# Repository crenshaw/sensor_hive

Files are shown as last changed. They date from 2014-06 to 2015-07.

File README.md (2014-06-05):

# Sensor Hive

Another chapter in the Internet of Things.  Sensing the world and pushing data to the cloud.

## About

Buildings are responsible for up to 40% of energy use.  Students and
faculty at the University of Portland are working towards a low-cost
solution for sensing building lighting systems in order to find ways
to provide more efficient lighting.

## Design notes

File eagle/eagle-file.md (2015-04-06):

## Eagle
#### This directory contains all relevant files for the manufacturing of the PCB for the Scio DAQ.

### `Final Gerber Output`
 - This directory contains the output files, which are sent to a manufacturer to produce the PCB for Scio. These can be viewed in `.txt` format (not useful), or using a gerber file viewer (available online).

### `PCB Final Design`
 - This directory contains all Eagle CAD design files. These can be viewed using Eagle. 

### `Bill of Materials`
 - This is an excel (`.xlsx`) file containing all required components needed for the PCB. Part names in file match the parts listed in `.brd` (Board) file, located in the `PCB Final Design` directory. These can be purchased using the links provided in the file.

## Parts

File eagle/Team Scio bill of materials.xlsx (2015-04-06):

Qty | Value | Device | Package | Description | Source
6 | .01uF | CAP_CERAMIC0805 | 805 | Ceramic Capacitors
2 | .1uF | C-US025-025X050 | C025-025X050 | CAPACITOR, American symbol
12 | 10K | R-US_M1206 | M1206 | RESISTOR, American symbol
12 | 10uF | C-USC0805K | C0805K | CAPACITOR, American symbol
12 | 1N4148 | DIODESOD-323F | SOD-323F | Diode | http://www.mouser.com/ProductDetail/Vishay-Semiconductors/1N4148WS-E3-18/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
4 | 2.2k | R-US_M1206 | M1206 | RESISTOR, American symbol
2 | 32.768 | CRYSTALTC38H | TC38H | CRYSTAL | http://www.mouser.com/Search/ProductDetail.aspx
2 | ARDUINO_R3_SHIELD | ARDUINO_R3_SHIELD | UNO_R3_SHIELD | Shield form compatible with the Arduino Uno R3.
2 | BAT | CR1220THM | CR1220-THM | CR1216/CR1220/CR1225 12mm 3V lithium coin cell | http://www.mouser.com/Search/ProductDetail.aspx
2 | DS1307 | DS1307 | DIL08 | DS1307 | http://www.mouser.com/ProductDetail/Maxim-IC/DS1307+/
12 | FERRITE | FERRITE0805 | 805 | Ferrite Bead | http://www.mouser.com/ProductDetail/TDK/MMZ1608B121C/
6 | J1 | 1X2-3.5MM | 1X2-3.5MM | 3.5mm Terminal block | http://www.adafruit.com/products/724?gclid=CNGU6IaB2cMCFRSGfgodyn0Agw
6 | LP298XS | LP298XS | SOT23-5L |  | http://www.mouser.com/ProductDetail/Texas-Instruments/LP2980IM5X-33-NOPB/?qs=7lkVKPoqpbYymzDtKIjHvQ%3D%3D
6 | MAX31855 | MAX31855 |  |  | http://www.mouser.com/ProductDetail/Maxim-Integrated/MAX31855KASA+/
2 | Coin Cell Holder |  |  |  | http://www.mouser.com/Search/ProductDetail.aspx

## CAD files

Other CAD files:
sensors/DAQ/Documentation/DAQ SCHEMATIC.dwg

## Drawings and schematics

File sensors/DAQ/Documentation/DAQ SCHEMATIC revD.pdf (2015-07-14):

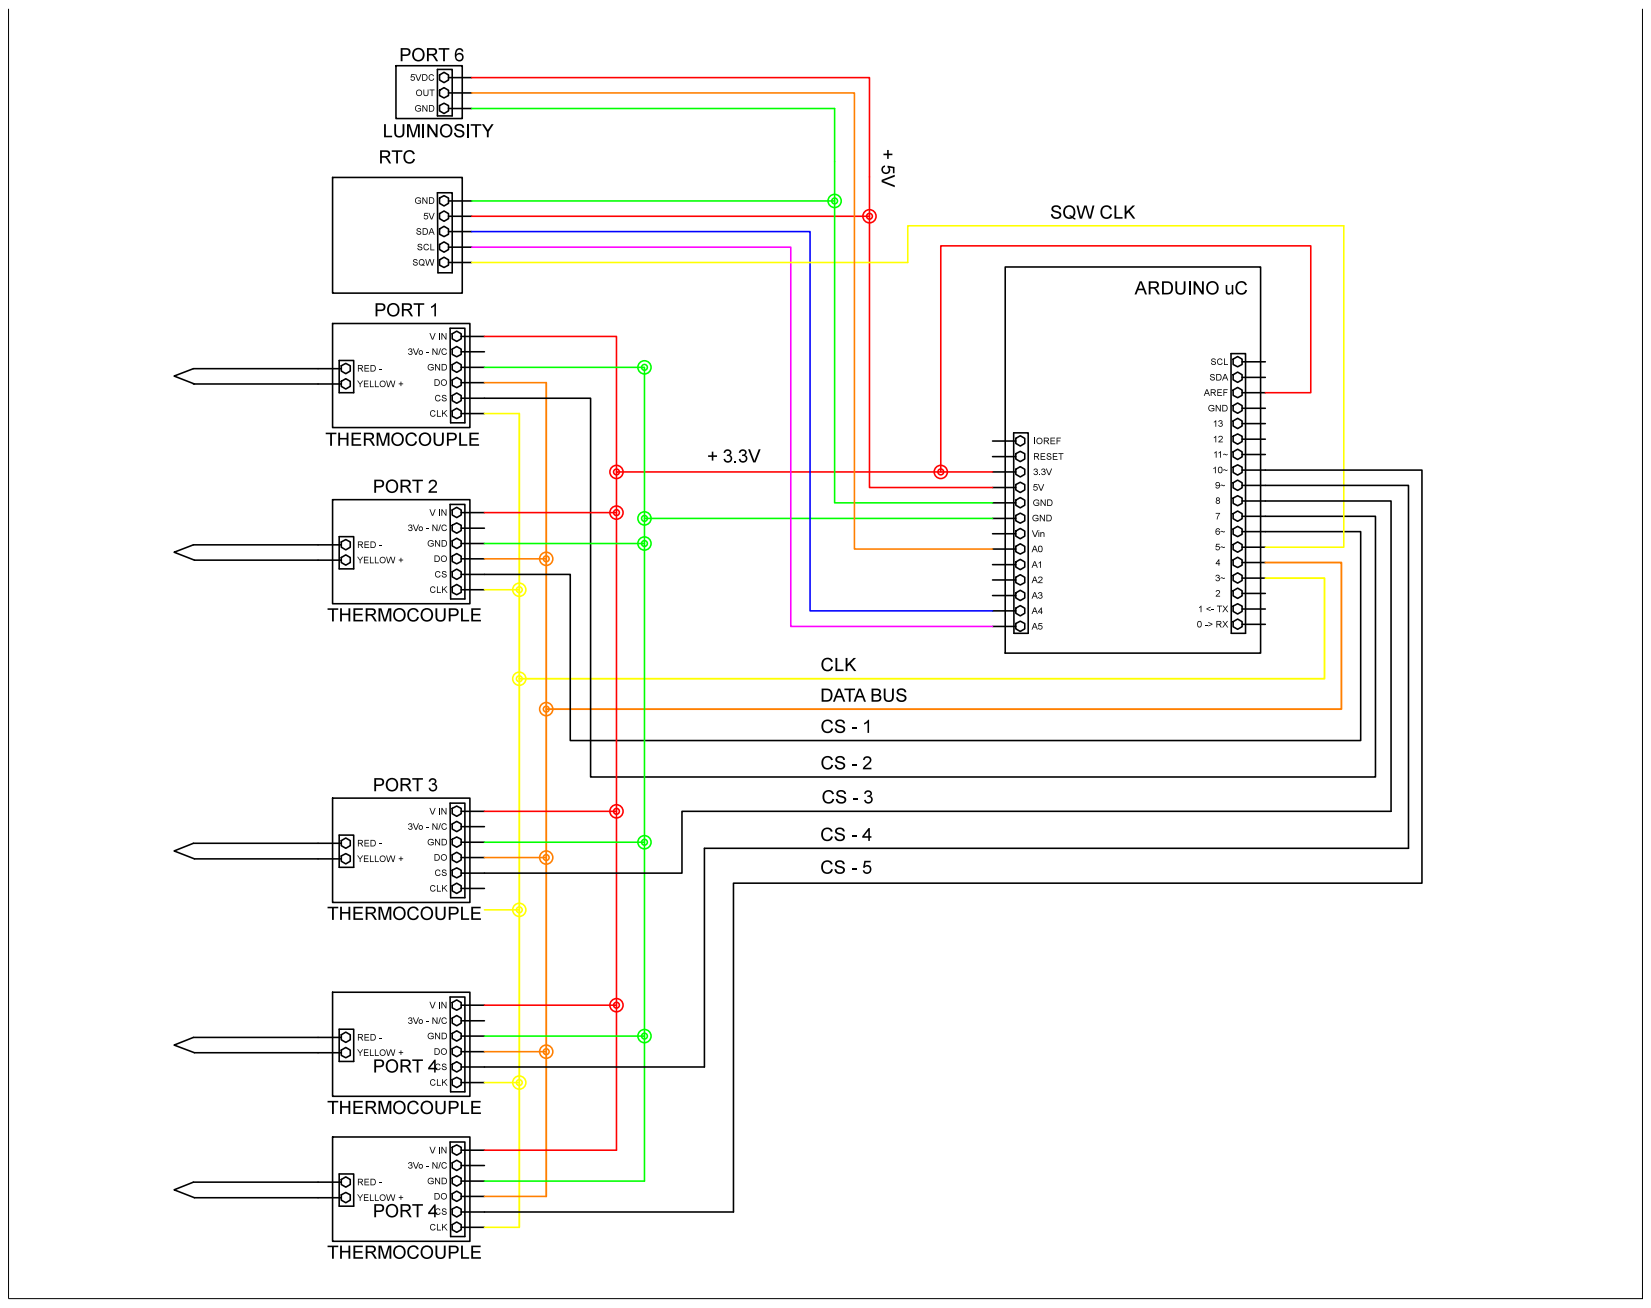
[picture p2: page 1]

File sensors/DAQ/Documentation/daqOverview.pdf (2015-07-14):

# Key:

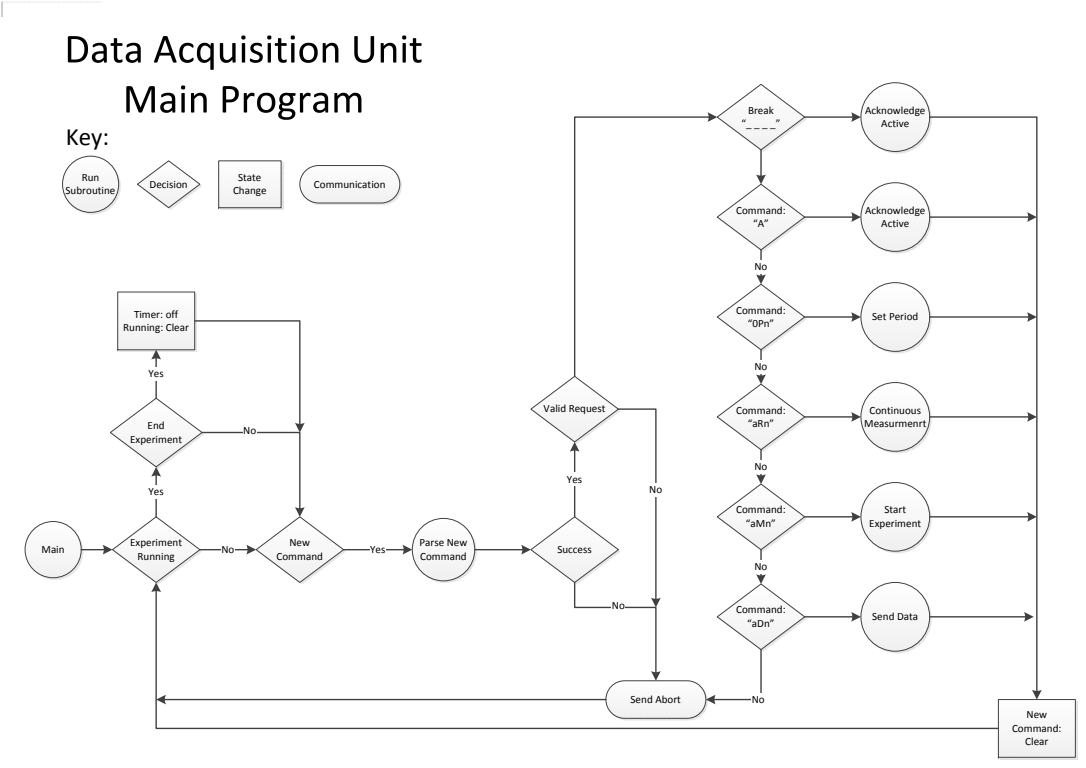
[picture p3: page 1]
Main; Experiment Running; End Experiment; Timer: off Running: Clear; Run; Subroutine; Decision; State Change; New Command; Parse New; Command; Success; Communication; Valid Request; Break “_ _ _ _”; Command: “A”; Command: “0Pn”; Command: “aRn”; Command: “aMn”; Command: “aDn”; Acknowledge Active; Set Period; Continuous Measurmenrt; Start Experiment; Send Data; Send Abort; New Command: Clear; Yes

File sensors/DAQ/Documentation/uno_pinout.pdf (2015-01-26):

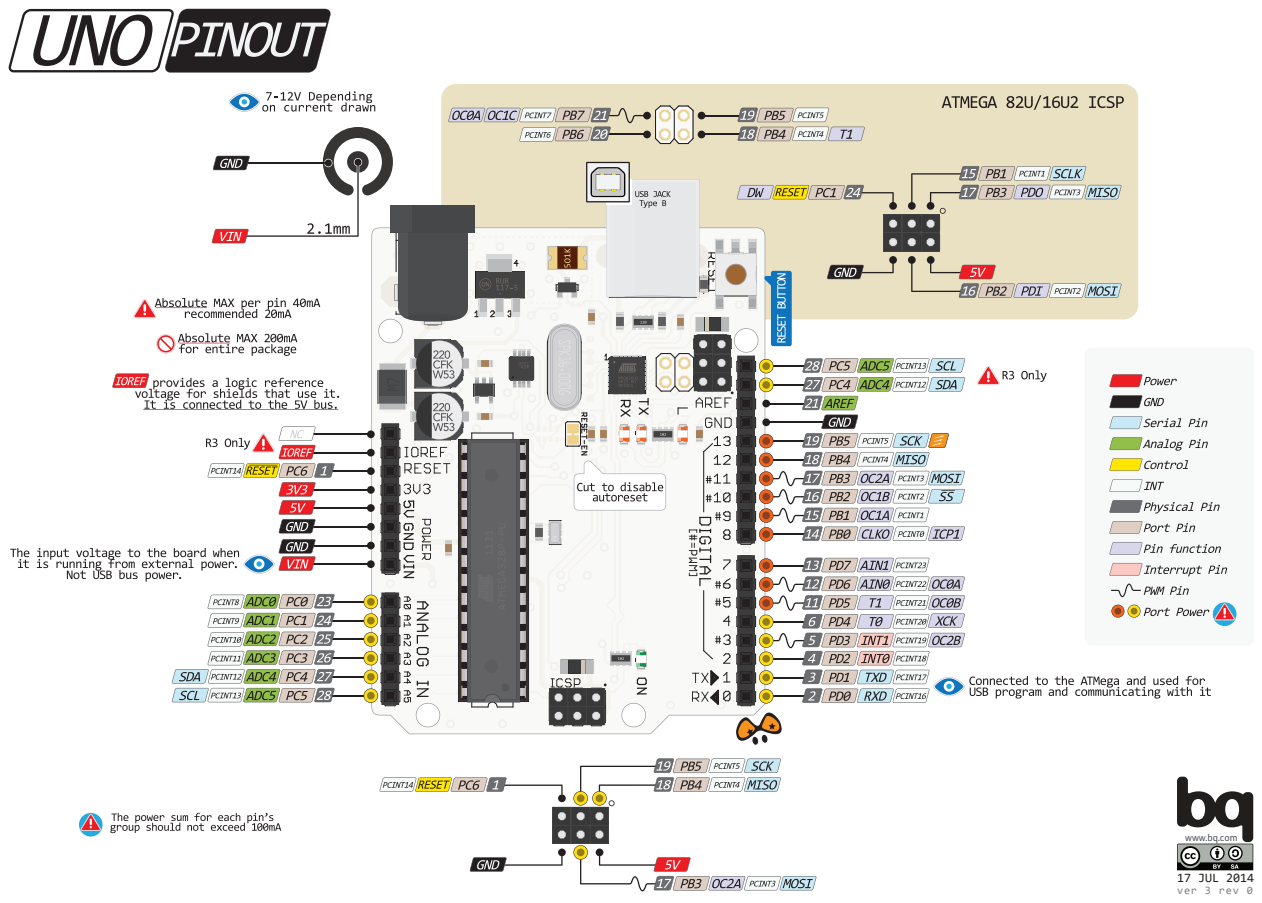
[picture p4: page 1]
17 JUL 2014 ver 3 rev 0

www.bq.com

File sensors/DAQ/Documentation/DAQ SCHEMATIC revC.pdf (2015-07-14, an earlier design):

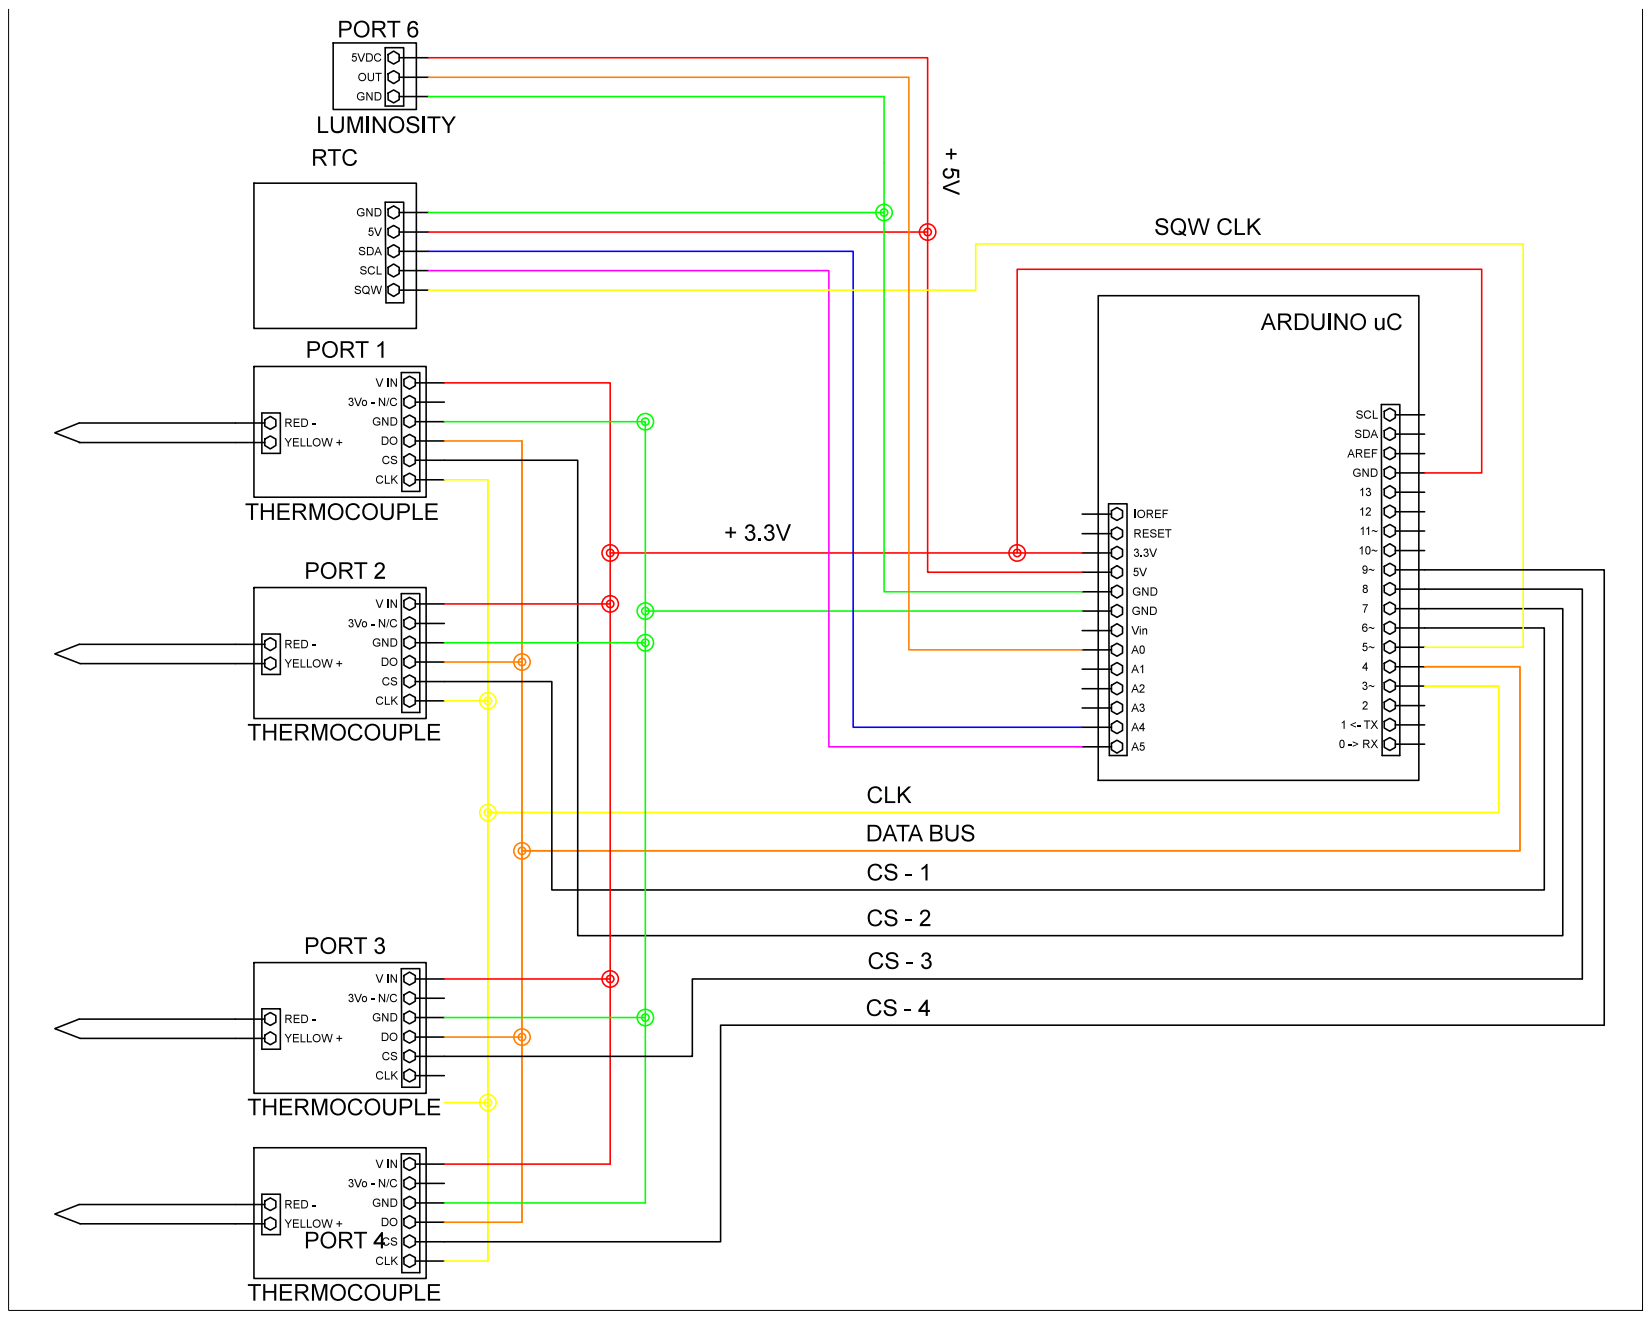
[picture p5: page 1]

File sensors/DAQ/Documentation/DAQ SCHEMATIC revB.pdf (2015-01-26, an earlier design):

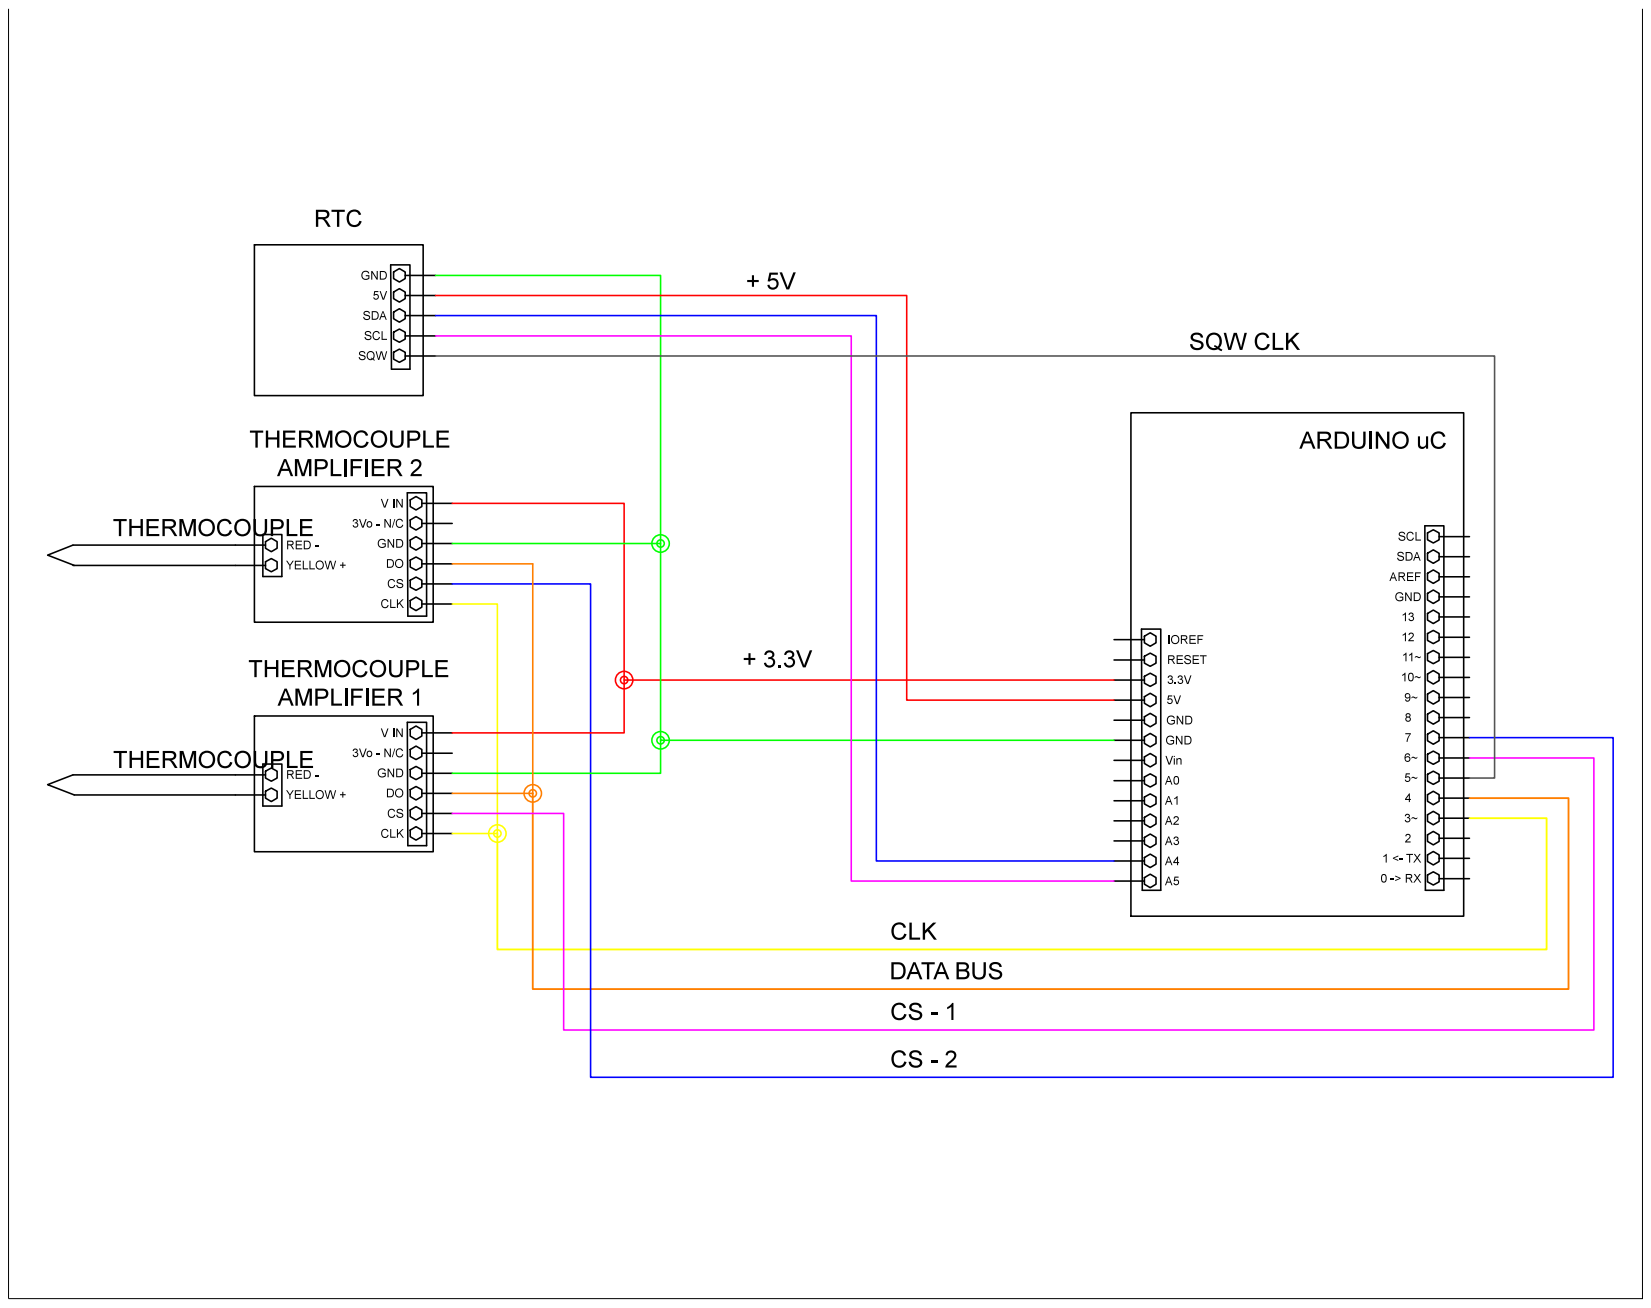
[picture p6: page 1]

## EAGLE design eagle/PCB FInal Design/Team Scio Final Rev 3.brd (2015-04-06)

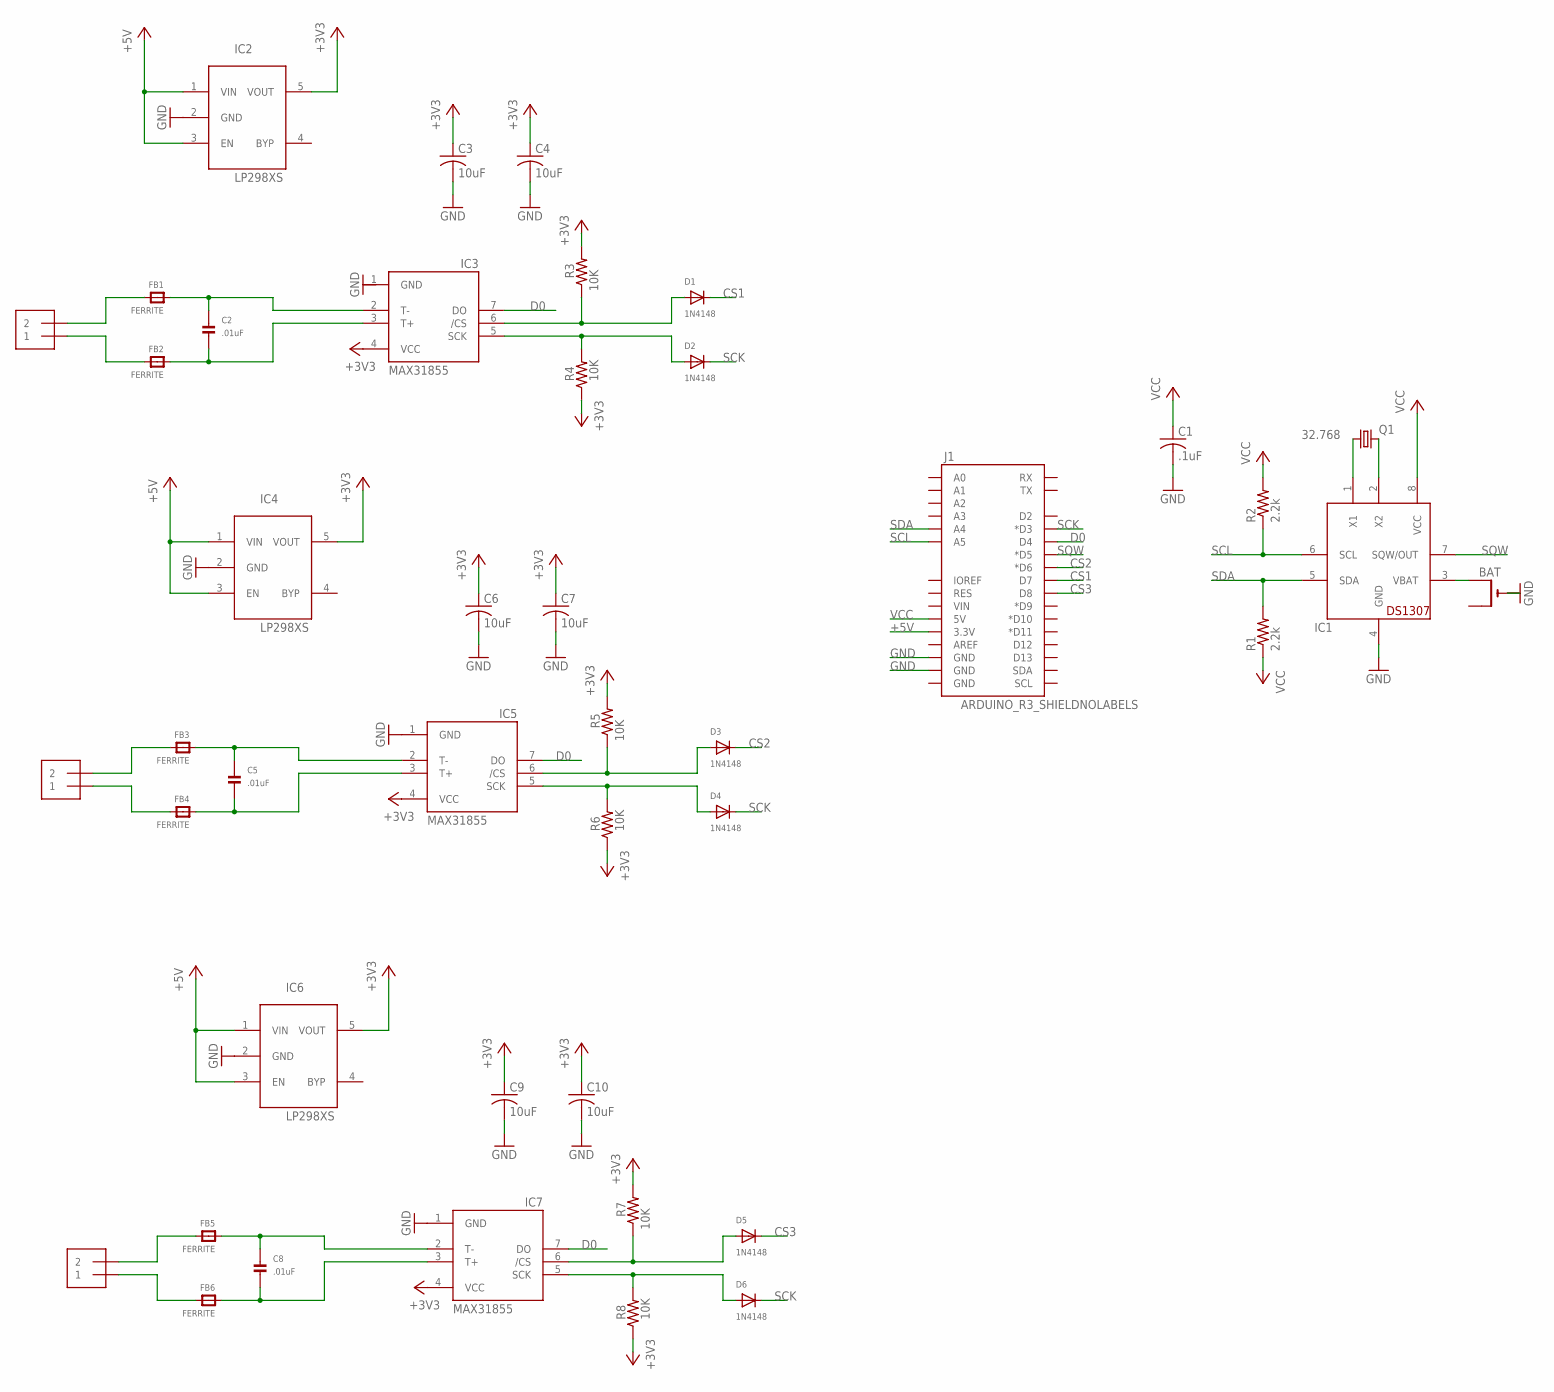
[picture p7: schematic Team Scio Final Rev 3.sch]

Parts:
C1: .1uF; C025-025X050
C2, C5, C8: .01uF; 0805
C3, C4, C6, C7, C9, C10: 10uF; C0805K
D1, D2, D3, D4, D5, D6: 1N4148; SOD-323F
FB1, FB2, FB3, FB4, FB5, FB6: FERRITE; 0805
IC1: DS1307; DIL08
IC2, IC4, IC6: LP298XS; SOT23-5L
IC3, IC5, IC7: MAX31855; SO08
J1: ARDUINO_R3_SHIELDNOLABELS; UNO_R3_SHIELD_NOLABELS
J2: J1; 1X2-3.5MM
J3, J4: 1X2-3.5MM
Q1: 32.768; TC38H
R1, R2: 2.2k; M1206
R3, R4, R5, R6, R7, R8: 10K; M1206
RTC: BAT; CR1220-THM

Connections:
+3V3: C3.1, C4.1, C6.1, C7.1, C9.1, C10.1, IC2.5 (VOUT), IC3.4 (VCC), IC4.5 (VOUT), IC5.4 (VCC), IC6.5 (VOUT), IC7.4 (VCC), R3.2, R4.1, R5.2, R6.1, R7.2, R8.1
+5V: IC2.1 (VIN), IC2.3 (EN), IC4.1 (VIN), IC4.3 (EN), IC6.1 (VIN), IC6.3 (EN), J1.3.3V
CS1: D1.C, J1.D7
CS2: D3.C, J1.D6 (*D6)
CS3: D5.C, J1.D8
D0: IC3.7 (DO), IC5.7 (DO), IC7.7 (DO), J1.D4
GND: C1.2, C3.2, C4.2, C6.2, C7.2, C9.2, C10.2, IC1.4 (GND), IC2.2 (GND), IC3.1 (GND), IC4.2 (GND), IC5.1 (GND), IC6.2 (GND), IC7.1 (GND), J1.GND@1 (GND), J1.GND@2 (GND), RTC.-
unnamed: IC1.3 (VBAT), RTC.+2 (+1)
unnamed: IC1.1 (X1), Q1.1
unnamed: IC1.2 (X2), Q1.2
unnamed: FB1.2, J2.2
unnamed: FB2.2, J2.1
unnamed: C2.1, FB1.1, IC3.2 (T-)
unnamed: C2.2, FB2.1, IC3.3 (T+)
unnamed: D1.A, IC3.6 (/CS), R3.1
unnamed: D2.A, IC3.5 (SCK), R4.2
unnamed: FB3.2, J3.2
unnamed: FB4.2, J3.1
unnamed: C5.1, FB3.1, IC5.2 (T-)
unnamed: C5.2, FB4.1, IC5.3 (T+)
unnamed: D3.A, IC5.6 (/CS), R5.1
unnamed: D4.A, IC5.5 (SCK), R6.2
unnamed: FB5.2, J4.2
unnamed: FB6.2, J4.1
unnamed: C8.1, FB5.1, IC7.2 (T-)
unnamed: C8.2, FB6.1, IC7.3 (T+)
unnamed: D5.A, IC7.6 (/CS), R7.1
unnamed: D6.A, IC7.5 (SCK), R8.2
SCK: D2.C, D4.C, D6.C, J1.D3 (*D3)
SCL: IC1.6 (SCL), J1.A5, R2.1
SDA: IC1.5 (SDA), J1.A4, R1.2
SQW: IC1.7 (SQW/OUT), J1.D5 (*D5)
VCC: C1.1, IC1.8 (VCC), J1.5V, R1.1, R2.2

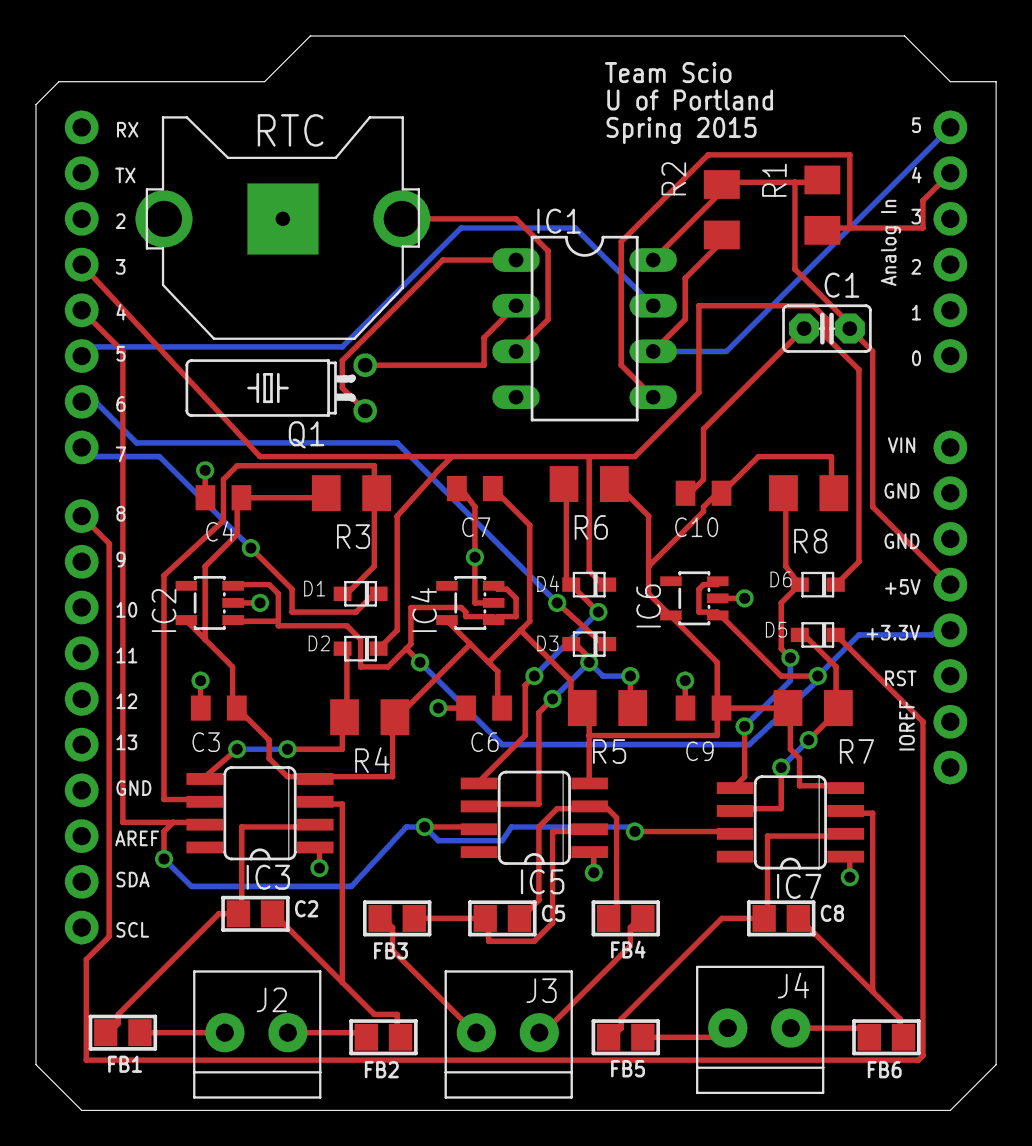
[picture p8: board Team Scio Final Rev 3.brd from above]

Board: 2 copper layers, 53.3 x 59.7 mm, 43 parts (0 on the bottom side), 33 nets.

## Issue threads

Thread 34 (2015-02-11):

Units sent from Scio app to remote server are incorrect

crenshaw, 2015-02-11:
Currently, the Scio app sends the remote server that ports 1 - 5 are in "Degrees" and port 6 is in "Degrees".  I'd like to change the former to "Celcius" and the latter to "Lux".

nwarlen, 2015-02-11:
Unable to test changes as I have no hardware but this should work: https://github.com/crenshaw/sensor_hive/pull/36

If the changes work properly, feel free to merge and close the PR.

epaulson10, 2015-02-12:
I have the units fixed in one of my branches. I think we forgot to merge
the changes because the semester ended and we got busy with other stuff.
I'll look at it tomorrow.
On Feb 12, 2015 1:17 AM, "Tanya L Crenshaw" <notifications@github.com>
wrote:

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

Closed 2015-04-15.

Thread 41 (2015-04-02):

Scio master application doesn't gracefully quit an experiment when a DAQ runs out of battery.

crenshaw, 2015-04-02:
The app insists that it is connected to the daq before:

1. Stopping an experiment.
2. Clearing an experiment configuration.

Except that when the daq has no power, it can't connect.  This seems silly.   The app should not insist on being connected before permitting 1 and 2 above.

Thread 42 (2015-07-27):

Light sensor reads maximum value.

crenshaw, 2015-07-27:
The analog light sensor reads its maximum value when any R-command is issued to the hardware.

crenshaw, 2015-07-27:
To avoid this problem, affirm that the AREF pin is connected to 3.3V on the Arduino Uno.

Closed 2015-07-27.

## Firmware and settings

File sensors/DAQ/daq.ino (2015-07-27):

#include <Wire.h>
#include <avr/wdt.h>
#include "Port.h"
#include "Experiment.h"
#include "Memory.h"
#include "miniSDI_12.h"

//#include "RTClib.h"

Memory memory;            //the memory class to manager EEPROM
Port ports;               //the porst class to manage current sensors
Experiment experiment;    //the experiment class to manage experiments

//RTC_DS1307 RTC;

boolean newCmd;              //new command flag
char command;                //command received from master
uint8_t port;                //desired port
uint32_t targetMeasurment;   //desired number of measurmnets.

void setup(){
    Serial.begin(9600);                            //baud rate
    Wire.begin();                                  //I2C coms
    memory.memorySetup();                          //init memory
    ports.portSetup(&memory);                      //init ports
    experiment.experimentSetup(&ports, &memory);   //init experiment
}

void loop(){
    //if serial command waiting to be recieved read it.
    if (Serial.available() > 0){
        //pars recieved command
        newCmd = readNewCmd (&command, &port,  &targetMeasurment);
        //bad command received send abort.
        if (!newCmd){
            respond(SDI_ABORT);
        }
    }
    if (newCmd){
        //switch to proper command
        switch (command){
            case 0:
                ports.isActive (port) ? respond(port) : respond (SDI_ABORT);
            break;
            case 'B':
                experiment.stopExperiment();
                respond(SDI_ABORT);
            break;
            case 'P':
                experiment.setPeriod (targetMeasurment);
            break;
            case 'R':
                experiment.startR (port, targetMeasurment);
            break;
            case 'M':
                experiment.startM (port, targetMeasurment);
            break;
            case 'D':
                ports.sendSavedData (targetMeasurment);
            break;
            default:
              respond(SDI_ABORT);
        }
    }
    //command processes no new command. wait for next command.
    newCmd = false;
}

//inturrupt service routine
//called on overflow of IRC1 or when experiment period has finished
ISR (EXPERIMENT_MEASURMENT){
    uint32_t time = experiment.updateCurrentPeriod();            //get the current period
    ports.savePortData(experiment.experimentBlock.port, time);   //read and save port data.
}

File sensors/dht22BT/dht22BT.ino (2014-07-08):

/**
 * dht22BT
 *
 * This small arduino sketch listens for the a command on the serial 
 * monitor and unconditionally replies with the temperature (C) and humidity (%)
 * captured by the DHT22 temperature and humidity sensor.  The response is 
 * formatted according to the miniSDI-12 protocol defined at the wiki page.
 *
 * This sketch executes successfully on the Arduino UNO equipped with
 * the Bluefruit EZ-Link Shield and DHT22 sensor.  It requires
 * the DHT library provided in the ./libraries/ directory. 
 * 
 * Based on the tutorial available at the adafruit site:
 * https://learn.adafruit.com/bluetooth-temperature-and-humidity-sensor
 *
 */
 
// Bluetooth temperature sensor
#include "DHT.h"

// Pin for the DHT sensor
#define DHTPIN 7    
#define DHTTYPE DHT22

// Create instance for the DHT sensor
DHT dht(DHTPIN, DHTTYPE);

// Setup
void setup(void)
{
  dht.begin();
  Serial.begin(9600);
}

void loop(void)
{
    // Get command
    if (Serial.available()) {

      String command;
      char c;
      
      // Read command loop
      while((c = Serial.read()) != '!')
      {
        // A value of -1 indicates that no data is available, so just throw out the byte.
        // Otherwise, save it so that we can repeat back the command (for debugging purposes).
        if(c != -1) 
        {
          command += String(c);
        }
      }
      
      command += "!";
       
      int h = (int)dht.readHumidity();
      int t = (int)dht.readTemperature();

      // Send data (temperature,humidity) according to the miniSDI-12 format.
      Serial.println(command);
      Serial.println("*,001,1,<time>,+" + String(t) + ".0" + ",+" + String(h) + ".0:");
     
      }
}

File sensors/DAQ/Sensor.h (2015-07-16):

/**
Sensors.h
Provides the class definitions for each sensor that is usable on the DAQ
@author: Zak Pearson
@since: January 2015
**/

#if (ARDUINO >= 100)
 #include "Arduino.h"
#else
 #include "WProgram.h"
#endif

#ifndef SENSOR_H
#define SENSOR_H

#include "Adafruit_MAX31855.h"       // temperature sensor class
#include "TSL2561.h"                 // RTC class
#include "Adafruit_GA1A12S202.h"     // Luminosity Class

// global constants for this class. All constants contributed to this class will begin with SENSOR_
#define SENSOR_TYPE_A 1
#define SENSOR_RETURN_TYPE_A double
#define SENSOR_TYPE_B 2
#define SENSOR_RETURN_TYPE_B float

/**
Class: Sensor
  A virtual class that provides the base functionality for any sensors 
  that will be implemented on the DAQ.This class should contain the functions
  that are common to all sensors as well as a virtual function for each individual sensor.
  The purpose of this classs is to be able to iterate over all sensors regardless of type.
  The state and type of the sensor are stored in the state and type variables. The type
  of sensor needs to be store to accomidate different return types.
Constructor: Sensor(void)
  Creates a sensor object
  Postcondition: state and type are undeclared. These will be declared in child classes.
Virtual Functions:
  virtual double measureTemp (void) = 0:
    virtual function that is define in the child class used to measure temperature.
  virtual float measureLight (void) = 0:
    virtual function that is define in the child class used to measure light intensity
  virtual uint8_t getError(void) = 0:
    virtual function this define in child class used to return any error codes specific to sensors
Getter Functions:
  boolean isActive (void):
    checks to see if a sensor is active returns true if it is
  int getType (void):
    returns the sensor type
Setter Functions:
  void setState (boolean newState):
    postcondition: state is set to newState
  void setType (int newType):
    postcondition: type is set to newType
**/
class Sensor{
  public:
    //constructor
    Sensor (void);
    //pure virtual functions to be define in child classes
    virtual double measureTemp (void) = 0;
    virtual float measureLight (void) = 0;
    virtual uint8_t getError(void) = 0;
    //member functions needed in each child class
    //getter
    boolean isActive (void);
    int getType (void){return type;};
    //setter
    void setState (boolean newState);
    void setType (int newType){type = newType;};
  private:
    boolean state;
    int type;
};

/**
Class: SensorTemp
  Inherits the Sensor class and provides functions for interacting with the Adafruit_MAX31855
  thermocouple and amplifier. 
Constructor: SensorTemp(Adafruit_MAX31855* sensorInit, boolean stateInit)
  Creates a SensorTemp object
  Postcondition: 
  Adafruit_MAX31855* sensor is set to sensorInit.
  boolean state is set to statInit
  type is set to SENSOR_TYPE_A
double measureTemp (void):
  returns temperature in degreese celcius
float measureLight (void):
  returns NULL
uint8_t getEffor(void):
  returns error code from Adafruit_MAX31855 temperature sensor
**/
class SensorTemp: public Sensor {
  public:
    //constructor
    SensorTemp (Adafruit_MAX31855* sensorInit, boolean stateInit);
    //member functions
    double measureTemp (void);
    float measureLight (void);
    uint8_t getError(void);
  private:
    Adafruit_MAX31855* sensor;
};

/**
Class: SensorTemp
  Inherits the Sensor class and provides functions for interacting with the Adafruit_GA1A12S202
  luminosity sensor. 
Constructor: SensorTemp(Adafruit_GA1A12S202* sensorInit, boolean stateInit)
  Creates a SensorLight object
  Postcondition: 
  Adafruit_GA1A12S202* sensor is set to sensorInit.
  boolean state is set to statInit
  type is set to SENSOR_TYPE_B
double measureTemp (void):
  returns NULL
float measureLight (void):
  returns light intensity in lumens
uint8_t getEffor(void):
  returns 0
  provides the possiblity to reutrn error codes for sensor
**/
class SensorLight: public Sensor{
  public:
    //constructor
    SensorLight (Adafruit_GA1A12S202* sensorInit, boolean stateInit);
    //member functions
    double measureTemp (void);
    float measureLight (void);
    uint8_t getError(void);
  private:
    Adafruit_GA1A12S202* sensor;
};


#endif

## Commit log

2014-06-05 Initial commit of a Google Packaged App that uses the experimental bluetooth API to list a few properties of a very specific bluetooth device.
2014-06-09 Adding functionality to devices.js. A listener has been added to respond to changes in the Bluetooth Adapter state. The connect() function now attempts to connect to a bluetooth device over a socket 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
2014-06-18 Adding a working Arduino sketch to measure and report the temperature and humidity captured by the DHT22 sensor. Work largely based on the tutorial provided at https://learn.adafruit.com/bluetooth-te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
2014-06-18 Created a Google Packaged App to list all serial devices on the Mac, including the AdaFruitEZ-Link237e-SPP device.
2014-06-18 Successfully able to send data to the Arduino and get a well-formed reply of temperature and humidity to the Chrome console over the bluetooth serial connection.
2014-06-20 Added a user-interface to the Google App. Buttons include: add, delete, connect, disconnect, and register. For now, only 'connect' is functional. The app is able to connect to a bluetooth device. The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
2014-06-20 Data received from the bluetooth serial device is now parsed and logged to the user interface. A 'refresh' button was added to resend requests to the bluetooth serial device.
2014-06-24 User interface now has a reasonably robust 'connect', 'disconnect' and 'refresh' button. User is not allowed to, say, disconnect a device that is already disconnected. A local daq object is now used 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
2014-06-30 Very unstylish code that runs the Arduino in two modes, manual and auto. Starts in manual mode by default.
2014-07-01 Moving towards getting my box and Arduino to implement the 0R1! command from our miniSD-12 protocol.
2014-07-03 Made font larger. Using a indicator for when a device is connected. Enforce that only 1 device may be selected at a time by the user. Keeping track of last device selected.
2014-07-04 Corrected bug: not all serial devices were showing up. Polished some of the user interface and added more info logging to the interface. Vistually and textually indicating when a device is connected 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
2014-07-07 Accepts commands A, R, and P. Sends data in correct format.
    [daq.ino]
2014-07-08 Altered how 'clear' works from ui.js. Added an info object. Added non-working buttons for configuring and running an experiment.'
2014-07-08 Midway through implementing 'configure experiment' and 'start experiment' for the user. Getting to this point required some refactoring in terms of how devices were locally registered. Now devices ca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
2014-07-10 Removed ';' from command terminator. The Arduino side hasn't implemented that yet. Corrected a bug in ui.indicate in which devices still had 'experiments' even after they had been removed from the lo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
2014-07-10 Runs commands a, 0Pn, and, aRn with correctly formatted response.
    [daq.ino]
2014-07-14 Corrected dataReprot to send correct sensor ID. Previosuly reported ID as 0 when it should have been 1. Updataed readNewCmd to id a command termination correctly.
    [daq.ino]
2014-07-14 Forgot to save the changes in the Arduino sketch. See previous commit message.
2014-07-14 Fixing a bug such that user's can start experiments before the device is connected. Fixing a bug such that user's can configure experiments while they are running. These are both undesireable situati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
2014-07-14 Tested fixes to miniSDI-12 protocol on Arduino side with user interface. Port number is now being reported correctly by Arduino. Tested fixes to bugs related to starting and configuring an experiment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
2014-07-14 Reduced number of buttons in local serial devices menu to be in line with Dr. Dillon's mental model of how the devices and experiments work. Added units back to configure experiment interface, but th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
2014-07-26 Changed the structure so the command and support functions were in their own implementation file. Implemented the M command trhough inturrupts. Currently the R command needs to be re-implemented
2014-08-01 The serialApp is now more robustly running R-style experiments. Experiment configuration is logged prettily to the experiment configuration window. It's now possible to run the same experiment over a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
2014-08-03 Implementation of the M and D commands are complete as seen from the master end. Currently M does not store any data on disk. All data is stored and retreived in volatile memory. A P and R commands a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
2014-08-04 Corrected a small typo in how disabled devices were being reported to the user interface.
2014-08-04 0R1 was waiting for the period to end. Fixed this issue. Now, aR1 commands in quick succession no longer wait for the period to elapse. Removed some unused variables as well.
    [daq.ino]
2014-08-07 Enhancing robustness of ui. A user may not test a daq while an R-style experiment is running. A user may not disable a device that is currently associated with an experiment. Added a button that will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
2014-08-08 Able to clear experiment settings. When an experiment is cleared, all devices associated with the experiment are also cleared.
2014-08-11 Runes Commands A, P, R, M, and D. Stores data to EEPROM and runs recovery algorithm on startup. Will continue an experiment on startup if the Arduino was reset or lost power while an experiment was r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
    [daq.ino]
2014-08-11 Removed a bebug flag from the EEPROMex library. Added a top address limit for writting to the EEPROM.Uncommenet a error check for D commmand that was commeneted out for debuging.
    [daq.ino]
2014-08-11 Application is now fairly robust against losing a device during an R-style experiment (desktop only logging). An onReceiveError() function is invoked when a connection is lost. This function marks a 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
2014-08-14 Added a stop button that makes use of the underlying mini-SDI12 break command to stop M-style experiments. Button is working and behaving as expected.
2014-08-14 Corrected a frustrating problem. Now detecting if R-style experiments are broken. If all the devices of an R-style experiment are disconnected, the experiment is assumed to be 'broken' and the experi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
2014-08-15 Removed the Serial Log to prepare for the user studies to come in the next couple of days. User studies will take place from the serialApp branch.
2014-08-16 Fixed a bug so that the daq qill repsond with the abort response if prompted with a D command before data is ready to be sent.
    [daq.ino]
2014-08-21 Able to gracefully reestablish a connection with the device during an M-style experiment. I notice some strange responses coming from the DAQ when the device is re-enabled, but I wonder if that is so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
2014-08-25 Removed three debug statments that were left in by mistake.
    [daq.ino]
2014-09-01 Initial commit of the hardware documentation. Includes reference sheets for the breakout boards from Adafruit, the pinout for the Arduino Uno, the data sheet for the ATmega328P, and a schematic of th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
2014-09-01 Parsed the datum string and inserted it into a table with headers. This is not ready to be pushed to production code. There are todos to be resolved after learning more about the codebase in first me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
2014-09-19 Checking this in for the night. This is really incomplete, I would recommend not looking at this until a future push. Currently have the indexedDB working, but extra functionality may be needed. Next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
2014-09-21 Fixed a bug so that the D command now sends data in time forward order
    [daq.ino]
2014-09-21 Upadted the aDn command so that it returns correct number of measuremetns. see issue number 5 for a complete description.
    [daq.ino]
2014-09-23 Removed strange characters from comments in EEPROMex.h. Arduino IDE was complaining about characters that were not UTF-8 encoded, and removing these characters corrected the complaining.
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2014-10-19 First commit of the reimplementation of the daq. Should correctly handel all commands from miniSDI_12 protocal. Currently there on no comments, those are to come.
    [daq.ino]
2014-10-19 A first push of the rewritten DAQ code. There are no comments as of yet, those are to come. This should be able to respond to all commands given per miniSDI_12 protocal.
    [DAQ SCHEMATIC.dwg]
2014-10-19 removed old code
    [DAQ SCHEMATIC.dwg]
2014-10-19 The new verison of the DAQ code. Allows for multiple sensor types. Should fully implement all commands sent via miniSDI_12 protocol.
    [DAQ SCHEMATIC.dwg]
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2014-11-02 Fixed a bug with the setting of the Timer/Counter 1 external clock pin. This is pin 5 on the arduino and needs to be set as INPUT_PULLUP. Previously was not set.
    [DAQ SCHEMATIC.dwg]
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2014-11-05 Removed debug statments and redundent code. Update DAQ schematic to match current DAQ layout. Now shows 5 thermocouples. Fixed an incorrect pin on DAQ schematic.
    [DAQ SCHEMATIC.dwg]
2014-11-08 Corrected the runnable.js implementation of polling for experiment data during an M-style experiment. The polling period is now set using the .p field of the experiment information, not the .period f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
2014-11-08 Fixed a bug with the D command. Now 0Da sends the last a measurments. Improved the structure of memory for cleaner code.
    [Experiment.cpp, Port.h, Sensor.h]
2014-11-17 Working on making some changes to make the app a little better. It now warns when there is no internet connection. It simply tells you that the POST failed. This kind of floods the message box, but i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
2015-03-30 Added relevant files
    [Team Scio Final Rev 3.brd, Team Scio Final Rev 3.sch, Team Scio bill of materials.xlsx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]
2015-04-03 Updated and added function headers and comments
    [DAQ SCHEMATIC.dwg]
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

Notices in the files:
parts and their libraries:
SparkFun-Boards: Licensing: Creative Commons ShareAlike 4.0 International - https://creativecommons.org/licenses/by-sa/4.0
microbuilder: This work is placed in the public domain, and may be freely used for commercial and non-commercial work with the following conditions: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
